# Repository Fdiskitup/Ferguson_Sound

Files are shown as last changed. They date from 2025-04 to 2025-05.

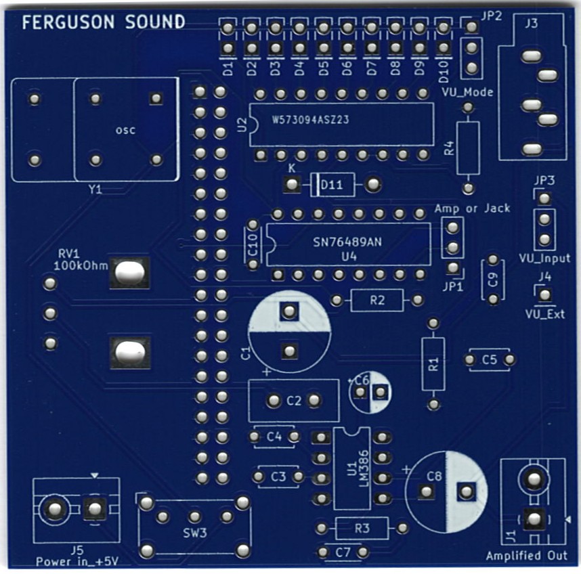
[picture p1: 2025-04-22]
PCB/Ferguson Sound FRONT.JPG

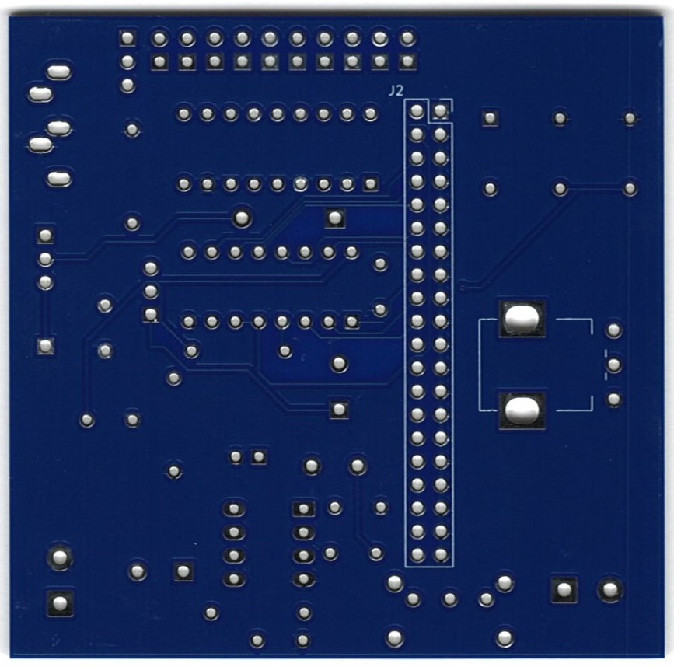
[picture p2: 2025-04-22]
PCB/Ferguson Sound PCB REAR.JPG

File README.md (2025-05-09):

# Ferguson_Sound
A soundcard for the Ferguson Big Board based on the SN76489 PSG sound chip.   
SN76489AN_soundboard1

The parallel port on the Ferguson Big Board uses the Z80 PIO to give 2 x 8bit bidirectional user ports.  
This soundcard was created to make use of port A. 

The board itself is rather simple consisting of 3 parts. 

1, The programmable sound generator chip (PSG) SN76489 and clock crystal oscillator. 
2, The amplifier based on he classic LM386 op amp chip. 
3, The VU meter using LM3915N-1 to pulse the LED's in tune to the music.  

This is derived from several sources 
https://github.com/bchiha/Ready-Z80/tree/main/16-SN76489_Sound_Generator 

https://github.com/jblang/SN76489

https://github.com/abaffa/z80cpm_emulator

What Does it do ? 
well it can output 3 channels of tones simultaneously, like a cord.  plus it can output a 4th noise channel for explosions gunshots etc. 
you can program it from basic, assembly, pascal, C etc.  
remember you will need to set up the PIO Port to be unidirectional - i.e. data mode as output, before trying to send data to the PSG.  
Included here are some basic files to get you started making noises.  
More importantly there is a program here M.COM that will mute the sound chip, because when it first turns on it tends to emit a random tone.  You'll want to stop this.

perhaps more interesting is the ability to play VGM files - these are Video Game Music files. 
The disk images here contain several files "filename.vgm" to play a vgm file simply type : 
VGMPLAY filename.VGM  [then Return/Enter]

to deal with the issue of speed I have recomplied the VGMPLAY.COM with different delays, 4VGMPLAY.COM is fastest while 7VGMPLAY.COM is slowest.
Speed mismatches occur because the PSG clock crystal (4MHZ) used may not be the same as that in the origin system.   

Ferguson Sound FRONT

The 270nF capacitors on the BOM are a strange value but it will be fine with 220nF or 300nF.  Hobby engineering. 

So you've built the card: 

On the Big Board make sure you set the jumpers pins 7-8, 9-10, 11-12, 13-14, 15-16 all on.  This sets the port for output only from the hardware.
see the single blue jumper and the 4 red jumpers.  
FS-1

You'll need to give the board +5V, I just brought a cable from the main board power block to the soundcard power block.  
The ground plane is connected to the 10 ground pins of the connector so you could just wire in a single 5V from the rails directly below the power connector.

JP1 = selects non-amplified or amplified output.  Non amplified goes to the 3.5 mm Jack then into powered speakers.   Amplified out can go direct into a 8ohm speaker or if to connect an RCA jack direct into a TV.   
JP2 = selects bar or dot mode for the VU meter (if installed) 
JP3 = selects to use internal audio for the VU meter, or external input for the VU meter (really just to test it.).    

I have tried with the 4MHZ full size dip 16 crystal oscillator, but I put in the footprint for the smaller oscillator package.  it should accomodate other frequencies 3.57mhz etc.  or you can steal a clock signal from the Z80-PIO pin 25 (Bandit !). 
similarly you can just jumper the power switch so its always on - you can always turn it down with the pot.       

So once it is built and jumpered, switch on and you should be treated to some excellent feedback.  
quickly boot into CPM and run the M.COM file to mute the noise, phew. 

The port resides at 08 and 09 hex

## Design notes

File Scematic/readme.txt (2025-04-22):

I used Kicad 9.0 to create the schematic.  
custom footprints were needed : SN76489, LM3915N-1, the 10kohm pot also needed to be modified to fit.

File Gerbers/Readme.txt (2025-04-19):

These Gerbers were used to make a set of boards with PCBWAY in April of 2025.  The Board was built and tested.  
comments : 
1, The 0.27uF (270nF) caps were substituted with 0.22uF (220nF) ceramics and the amp circuit works fine.
2, The slide switch on the power line stops the random feedback at power on, I did not have the exact switch so used a substitute.  The M.com file mutes the PSG on boot and if needed with a hanging note etc. 
3, The VU meter bottom 2 LED's stay on at all times and the sensitivity of the VU meter is attenuated too much by the volume POT.  Resistor and/or cap values need fine tuning.

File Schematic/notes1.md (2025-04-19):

3 main areas to the schematic 

psg and clock to non amplified output 
amplifier circuit
vu meter circuit 

is possible to make just the psg and leave the rest unpopulated, or psg + amp only

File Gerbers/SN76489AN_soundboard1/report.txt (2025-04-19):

Plotted to 'C:\Users\spenc\OneDrive\Documents\KiCad\9.0\projects\SN76489AN-1\SN76489AN_soundboard1\SN76489AN_soundboard1-F_Cu.gbr'.
Plotted to 'C:\Users\spenc\OneDrive\Documents\KiCad\9.0\projects\SN76489AN-1\SN76489AN_soundboard1\SN76489AN_soundboard1-B_Cu.gbr'.
Plotted to 'C:\Users\spenc\OneDrive\Documents\KiCad\9.0\projects\SN76489AN-1\SN76489AN_soundboard1\SN76489AN_soundboard1-F_Paste.gbr'.
Plotted to 'C:\Users\spenc\OneDrive\Documents\KiCad\9.0\projects\SN76489AN-1\SN76489AN_soundboard1\SN76489AN_soundboard1-B_Paste.gbr'.
Plotted to 'C:\Users\spenc\OneDrive\Documents\KiCad\9.0\projects\SN76489AN-1\SN76489AN_soundboard1\SN76489AN_soundboard1-F_Silkscreen.gbr'.
Plotted to 'C:\Users\spenc\OneDrive\Documents\KiCad\9.0\projects\SN76489AN-1\SN76489AN_soundboard1\SN76489AN_soundboard1-B_Silkscreen.gbr'.
Plotted to 'C:\Users\spenc\OneDrive\Documents\KiCad\9.0\projects\SN76489AN-1\SN76489AN_soundboard1\SN76489AN_soundboard1-F_Mask.gbr'.
Plotted to 'C:\Users\spenc\OneDrive\Documents\KiCad\9.0\projects\SN76489AN-1\SN76489AN_soundboard1\SN76489AN_soundboard1-B_Mask.gbr'.
Plotted to 'C:\Users\spenc\OneDrive\Documents\KiCad\9.0\projects\SN76489AN-1\SN76489AN_soundboard1\SN76489AN_soundboard1-Edge_Cuts.gbr'.
Created Gerber job file 'C:\Users\spenc\OneDrive\Documents\KiCad\9.0\projects\SN76489AN-1\SN76489AN_soundboard1\SN76489AN_soundboard1-job.gbrjob'.
Info: Done.

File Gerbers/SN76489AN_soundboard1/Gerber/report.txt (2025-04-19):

Plotted to 'C:\Users\spenc\OneDrive\Documents\KiCad\9.0\projects\SN76489AN-1\SN76489AN_soundboard1\Gerber\SN76489AN_soundboard1-F_Cu.gbr'.
Plotted to 'C:\Users\spenc\OneDrive\Documents\KiCad\9.0\projects\SN76489AN-1\SN76489AN_soundboard1\Gerber\SN76489AN_soundboard1-B_Cu.gbr'.
Plotted to 'C:\Users\spenc\OneDrive\Documents\KiCad\9.0\projects\SN76489AN-1\SN76489AN_soundboard1\Gerber\SN76489AN_soundboard1-F_Paste.gbr'.
Plotted to 'C:\Users\spenc\OneDrive\Documents\KiCad\9.0\projects\SN76489AN-1\SN76489AN_soundboard1\Gerber\SN76489AN_soundboard1-B_Paste.gbr'.
Plotted to 'C:\Users\spenc\OneDrive\Documents\KiCad\9.0\projects\SN76489AN-1\SN76489AN_soundboard1\Gerber\SN76489AN_soundboard1-F_Silkscreen.gbr'.
Plotted to 'C:\Users\spenc\OneDrive\Documents\KiCad\9.0\projects\SN76489AN-1\SN76489AN_soundboard1\Gerber\SN76489AN_soundboard1-B_Silkscreen.gbr'.
Plotted to 'C:\Users\spenc\OneDrive\Documents\KiCad\9.0\projects\SN76489AN-1\SN76489AN_soundboard1\Gerber\SN76489AN_soundboard1-F_Mask.gbr'.
Plotted to 'C:\Users\spenc\OneDrive\Documents\KiCad\9.0\projects\SN76489AN-1\SN76489AN_soundboard1\Gerber\SN76489AN_soundboard1-B_Mask.gbr'.
Plotted to 'C:\Users\spenc\OneDrive\Documents\KiCad\9.0\projects\SN76489AN-1\SN76489AN_soundboard1\Gerber\SN76489AN_soundboard1-Edge_Cuts.gbr'.
Created Gerber job file 'C:\Users\spenc\OneDrive\Documents\KiCad\9.0\projects\SN76489AN-1\SN76489AN_soundboard1\Gerber\SN76489AN_soundboard1-job.gbrjob'.
Info: Done.

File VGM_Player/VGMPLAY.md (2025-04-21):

The VGM (Video Game Music) player .com file is used by typing :
6VGMPLAY Filename.VGM 
where file name is the name of the VGM you want to play.  simple enough. 
7VGMPLAY.COM and 6VGMPLAY are basically the same but a single NOP delay difference means that 6VGMPLAY.COM plays the files slightly faster.  
Files come in a mixture of formats, VGM files from the BBC micro use a 4mhz clock chip.  Other formats, Sega, etc, use a 3.57 NTSC 60Hz clock.  
Add to that the possibility for a 2.5mhz Ferguson cpu clock with the PSG requirement for 32 clock cycles between data writes and you can see how a variable delay might be needed.  
Ideally we could add it as a command line switch or even a keypress during playback.  A volume attenuation control migt also be nice during playback.  

M.COM   this is the mute ! when the chip turns on it plays whatever random noise is in the buffer.  you'll want to mute it as soon as possible after you boot cpm.

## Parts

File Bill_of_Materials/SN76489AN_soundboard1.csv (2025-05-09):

Reference | Qty | Value | Notes | Footprint | Datasheet/note | Supplier | part | Weblink | DIGIKEY NUMBER
C1,C8 | 2 | 470uF |  | Capacitor_THT:CP_Radial_D10.0mm_P2.50mm | ~ | digikey | UHE1E471MPD6 | https://www.digikey.com/en/products/detail/nichicon/UHE1E471MPD6/589294 |  | Electrolytic
C2 | 1 | 47pF |  | Capacitor_THT:CP_Radial_D5.0mm_P2.50mm | ~ | digikey | CD15ED470JO3 | https://www.digikey.com/en/products/detail/cornell-dubilier-knowles/CD15ED470JO3/337841
C3,C4,C5 | 3 | 270nF |  | Capacitor_THT:CP_Radial_D5.0mm_P2.50mm | 220, 300 use what is close | digikey |  |  |  | Ceramic capacitor
C6 | 1 | 10uF |  | Capacitor_THT:CP_Radial_D5.0mm_P2.50mm | ~ | digikey | 493-13450-1-ND | https://www.digikey.com/en/products/detail/nichicon/UVZ1E100MDD1TD/4342006 |  | Electrolytic
C7,C10 | 2 | 100nF | 0.1uF | Capacitor_THT:CP_Radial_D5.0mm_P2.50mm | ~ | digikey | K104K15X7RF53H5 | https://www.digikey.com/en/products/detail/vishay-beyschlag-draloric-bc-components/K104K15X7RF53H5/2820505
C9 | 1 | 220nF |  | Capacitor_THT:CP_Radial_D5.0mm_P2.50mm | used substitute 300nF |  |  |  |  | Electrolytic
D1 to D10 | 10 | LED |  | LED_THT:LED_D3.0mm | square LED from Ali Express 2mm x 5 mm | ALI Express
D11 | 1 | 1N4007 |  | Diode_THT:D_DO-41_SOD81_P10.16mm_Horizontal | http://www.vishay.com/docs/88503/1n4001.pdf | digikey | 1N4007GOS-ND | https://www.digikey.com/en/products/detail/onsemi/1N4007G/1485479 |  | ceramic
J2 | 1 | GPIO_Header |  | Connector_PinSocket_2.54mm:PinSocket_2x20_P2.54mm_Vertical | Aliexpress
J3 | 1 | AudioJack3_Switch |  | Connector_Audio:Jack_3.5mm_PJ31060-I_Horizontal | mono output only 2 pins needed | digikey | SJ1-3533NG / SJ1-3535NG | https://www.digikey.com/en/products/detail/same-sky-formerly-cui-devices/SJ1-3533NG/738701 https://www.digikey.com/en/products/detail/same-sky-formerly-cui-devices/SJ1-3535NG/738699 |  | might be better top connect, side screws
J4 | 1 | Ext_Pin |  | Connector_PinHeader_2.54mm:PinHeader_1x01_P2.54mm_Horizontal | optional | digikey | 61300311121 | https://www.digikey.com/en/products/detail/w%C3%BCrth-elektronik/61300311121/4846825
J1, J5 | 2 | Power in_+5V, Speaker out |  | TerminalBlock:TerminalBlock_MaiXu_MX126-5.0-02P_1x02_P5.00mm | 5V in and speaker out (consider RF out) |  | 283-5130-ND | https://www.digikey.com/en/products/detail/eaton-electronics-division/EM366002/7718144
R1 | 1 | 1MOhm |  | Resistor_THT:R_Axial_DIN0207_L6.3mm_D2.5mm_P10.16mm_Horizontal | ~ | digikey | A105943CT-ND | https://www.digikey.com/en/products/detail/te-connectivity-passive-product/YR1B1M0CC/2380511
R2,R4 | 2 | 10kOhm |  | Resistor_THT:R_Axial_DIN0207_L6.3mm_D2.5mm_P10.16mm_Horizontal | ~ | digikey | MFR-25FRF52-10K | https://www.digikey.com/en/products/detail/yageo/MFR-25FRF52-10K/14626
R3 | 1 | 10_Ohm |  | Resistor_THT:R_Axial_DIN0207_L6.3mm_D2.5mm_P10.16mm_Horizontal | ~ | digikey | MFR-25FBF52-11R | https://www.digikey.com/en/products/detail/yageo/MFR-25FBF52-11R/4187
RV1 | 1 | 100kOhm |  | Potentiometer_THT:Potentiometer_Bourns_PTV09A-1_Single_Vertical | unique footprint ? | digikey | PDB12-M4251-104BF-ND | https://www.digikey.com/en/products/detail/bourns-inc/PDB12-M4251-104BF/3780670
JP1, SW1, SW2 | 3 | Amp or Jack, VU_Mode, VU_input |  | Connector_PinHeader_2.54mm:PinHeader_1x03_P2.54mm_Vertical | ~ | digikey | 61300311121 | https://www.digikey.com/en/products/detail/w%C3%BCrth-elektronik/61300311121/4846825
SW3 | 1 | Power_Switch |  | Button_Switch_THT:SW_E-Switch_EG1224_SPDT_Angled | (cuts out the noise, volume also works) | digikey | EG2585-ND | https://www.digikey.com/en/products/detail/e-switch/EG1224/502052
U1 | 1 | LM386 |  | Package_DIP:DIP-8-16_W7.62mm_Socket_LongPads | http://www.ti.com/lit/ds/symlink/lm386.pdf | digikey | LM386N-4/NOPB | https://www.digikey.com/en/products/detail/texas-instruments/LM386N-4-NOPB/148192
U2 | 1 | LM3915N |  | Package_DIP:DIP-18_W7.62mm | https://www.ti.com/lit/ds/symlink/lm3914.pdf | ALI Express
U4 | 1 | SN76489AN |  | Package_DIP:DIP-16_W7.62mm | SN76489AN | ALI Express
Y1 | 1 | ACO-4.0MHz |  | Oscillator:Oscillator_DIP-14 | http://www.conwin.com/datasheets/cx/cx030.pdf | EBAY | ECS-2100A-040 | https://www.digikey.com/en/products/detail/ecs-inc/ECS-2100A-040/79196 |  | from Digikey
U2 | 1 | LM3915N |  |  |  | Package_DIP:DIP-18_W7.62mm | https://www.ti.com/lit/ds/symlink/lm3914.pdf |  |  | From Ebay
U4 | 1 | SN76489AN |  |  |  | Package_DIP:DIP-16_W7.62mm | SN76489AN |  |  | From Ali Express
Y1 | 1 | ACO-4.0MHz |  |  |  | Oscillator:Oscillator_DIP-14 | http://www.conwin.com/datasheets/cx/cx030.pdf |  |  | From Ali Express / Digi | https://www.digikey.com/en/products/detail/ecs-inc/ECS-2100A-040/79196

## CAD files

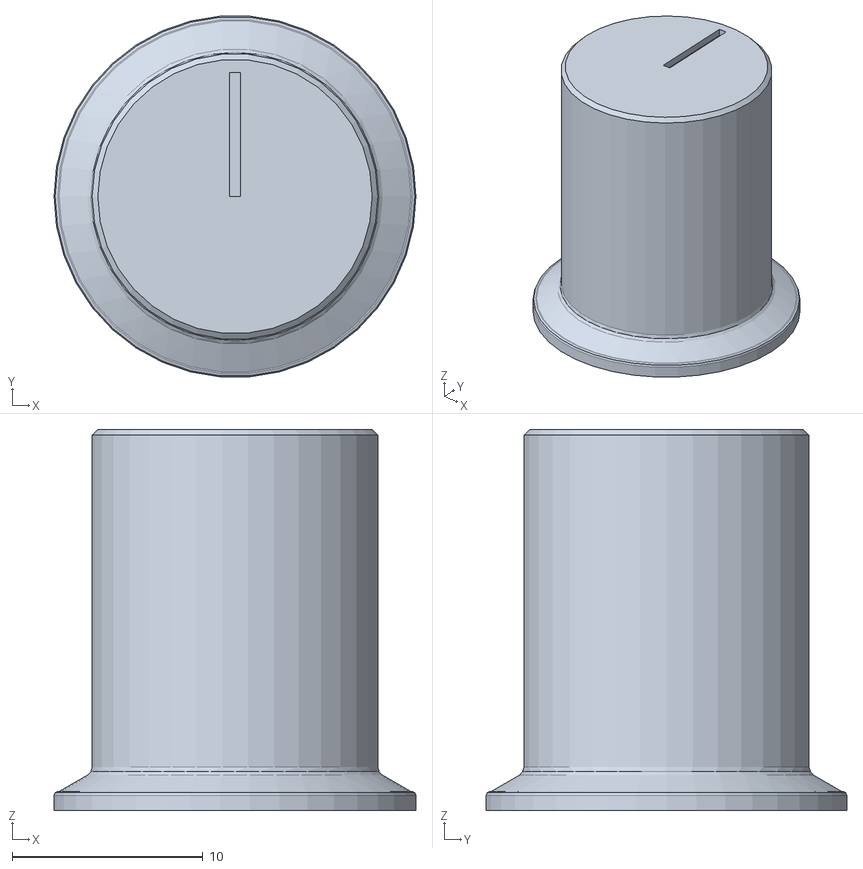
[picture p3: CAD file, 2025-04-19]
3D_prints/Poti_knob.stl
19.0 x 18.9 x 20.0

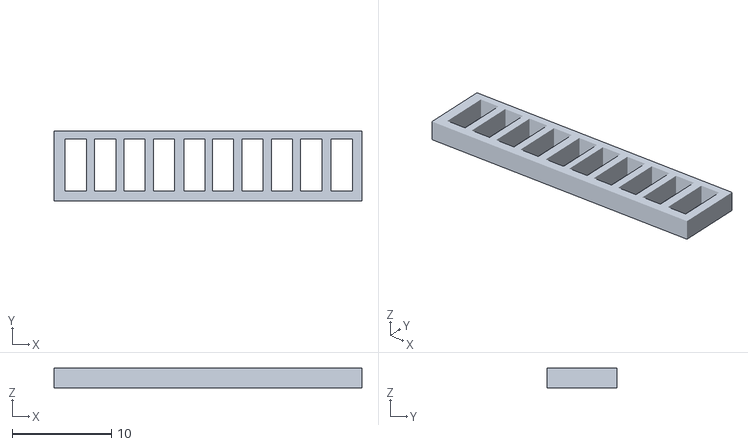
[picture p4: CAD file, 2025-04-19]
3D_prints/led guide.stl
31.0 x 7.00 x 2.00

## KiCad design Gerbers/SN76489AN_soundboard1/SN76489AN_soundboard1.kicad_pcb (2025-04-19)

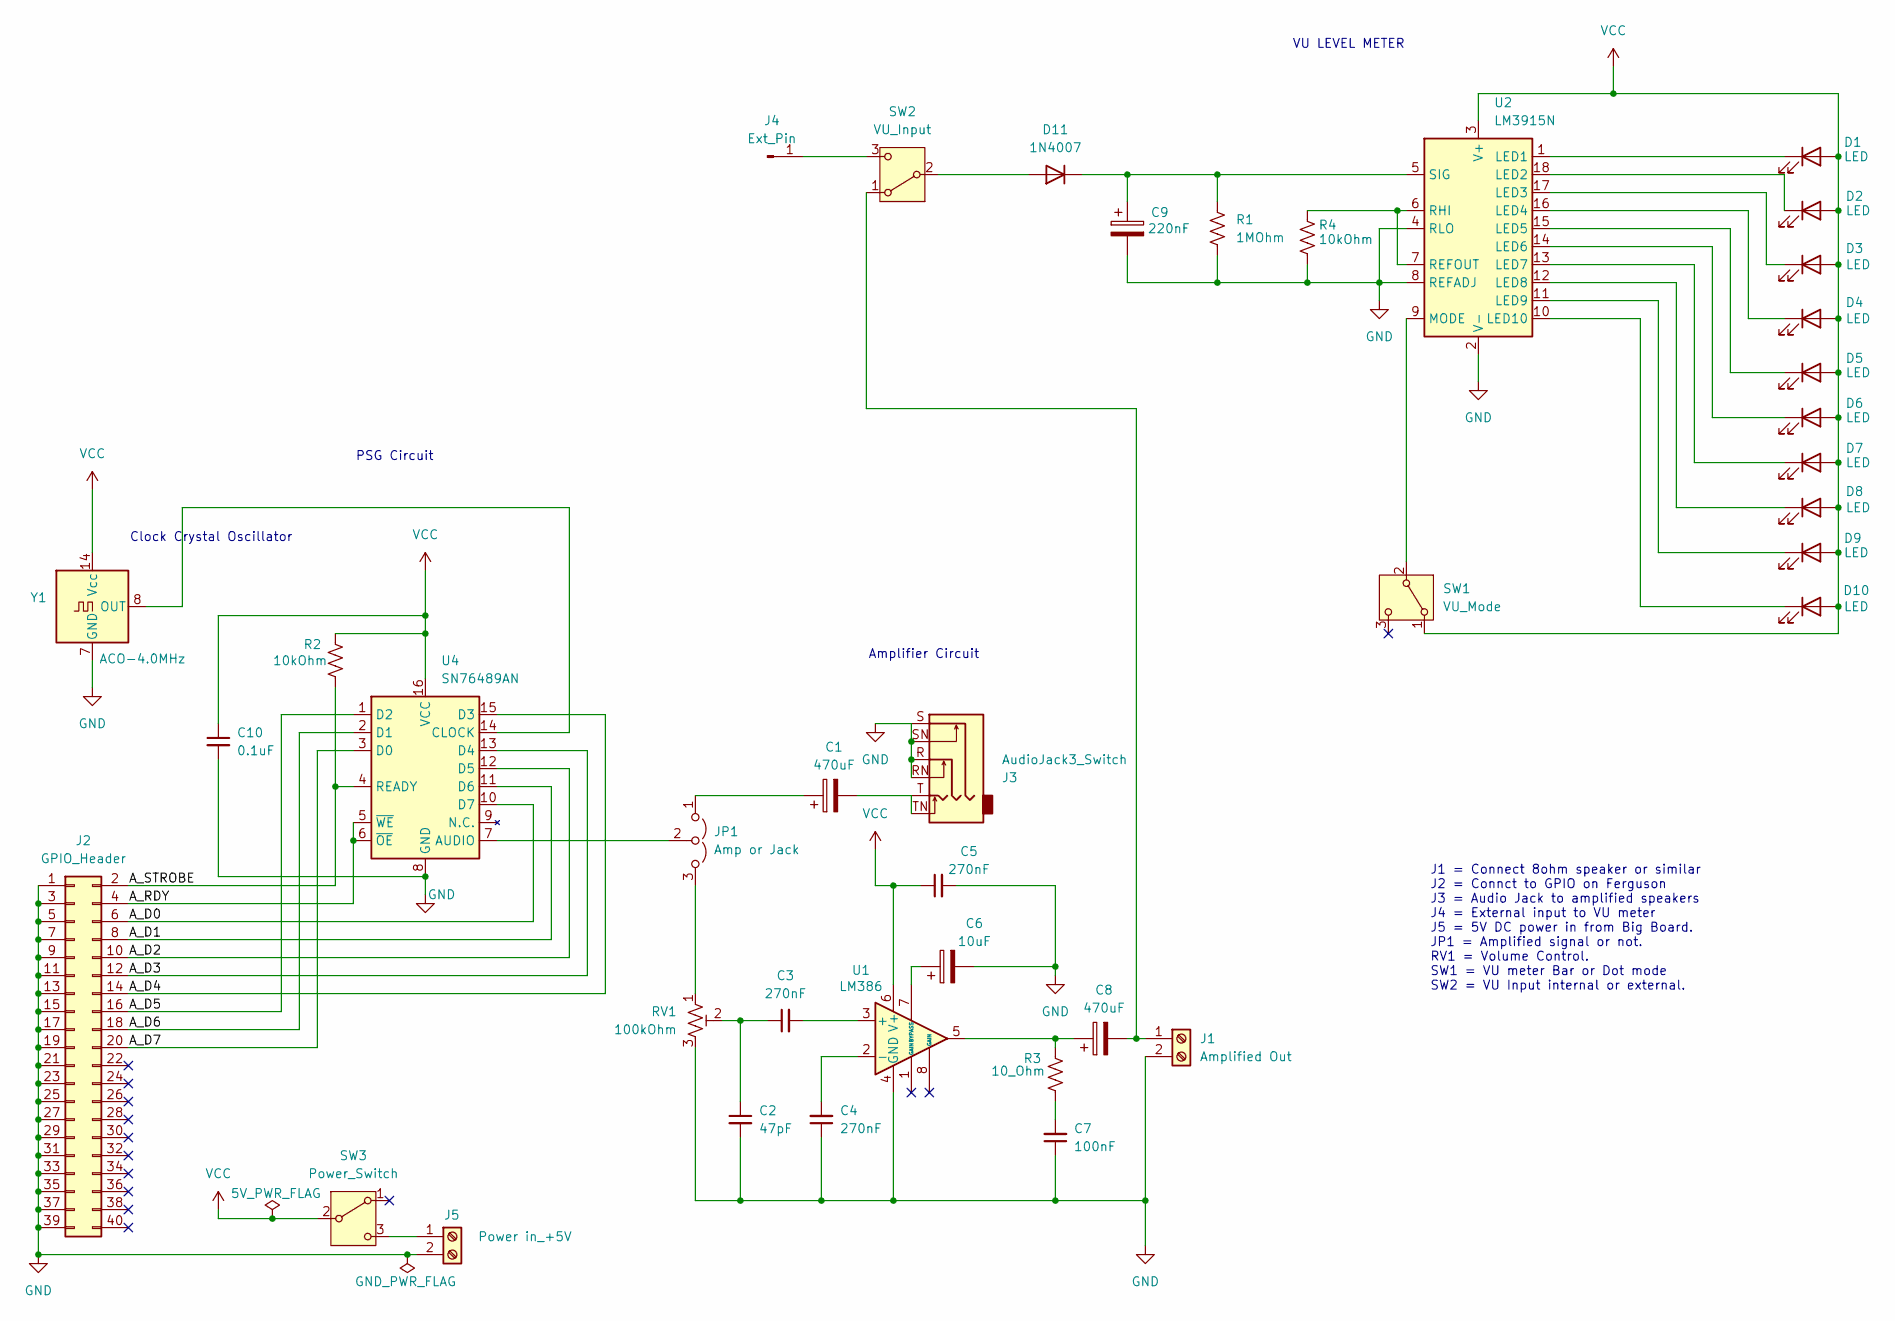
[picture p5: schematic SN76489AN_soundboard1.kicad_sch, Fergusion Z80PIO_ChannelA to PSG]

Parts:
C1: 470uF; CP_Radial_D10.0mm_P2.50mm
C2: 47pF; CP_Radial_D5.0mm_P2.50mm
C3, C4, C5: 270nF; CP_Radial_D5.0mm_P2.50mm
C6: 10uF; CP_Radial_D5.0mm_P2.50mm
C7: 100nF; CP_Radial_D5.0mm_P2.50mm
C8: 470uF; C_Radial_D10.0mm_H12.5mm_P5.00mm
C9: 220nF; CP_Radial_D5.0mm_P2.50mm
C10: 0.1uF; CP_Radial_D5.0mm_P2.50mm
D1, D2, D3, D4, D5, D6, D7, D8, D9, D10: LED; LED_D3.0mm
D11: 1N4007; D_DO-41_SOD81_P10.16mm_Horizontal
J1: Amplified Out; TerminalBlock_MaiXu_MX126-5.0-02P_1x02_P5.00mm
J2: GPIO_Header; PinSocket_2x20_P2.54mm_Vertical
J3: AudioJack3_Switch; Jack_3.5mm_PJ31060-I_Horizontal
J4: Ext_Pin; PinHeader_1x01_P2.54mm_Horizontal
J5: Power in_+5V; TerminalBlock_MaiXu_MX126-5.0-02P_1x02_P5.00mm
JP1: Amp or Jack; PinHeader_1x03_P2.54mm_Vertical
R1: 1MOhm; R_Axial_DIN0207_L6.3mm_D2.5mm_P10.16mm_Horizontal
R2, R4: 10kOhm; R_Axial_DIN0207_L6.3mm_D2.5mm_P10.16mm_Horizontal
R3: 10_Ohm; R_Axial_DIN0207_L6.3mm_D2.5mm_P10.16mm_Horizontal
RV1: 100kOhm; Potentiometer_Bourns_PTV09A-1_Single_Vertical
SW1: VU_Mode; PinHeader_1x03_P2.54mm_Vertical
SW2: VU_Input; PinHeader_1x03_P2.54mm_Vertical
SW3: Power_Switch; SW_E-Switch_EG1224_SPDT_Angled
U1: LM386; DIP-8-16_W7.62mm_Socket_LongPads
U2: LM3915N; DIP-18_W7.62mm
U4: SN76489AN; DIP-16_W7.62mm
Y1: ACO-4.0MHz; Oscillator_DIP-14

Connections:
/A_D0: J2.6, U4.10 (D7)
/A_D1: J2.8, U4.11 (D6)
/A_D2: J2.10, U4.12 (D5)
/A_D3: J2.12, U4.13 (D4)
/A_D4: J2.14, U4.15 (D3)
/A_D5: J2.16, U4.1 (D2)
/A_D6: J2.18, U4.2 (D1)
/A_D7: J2.20, U4.3 (D0)
/A_RDY: J2.4, U4.5 (~WE), U4.6 (~OE)
/A_STROBE: J2.2, R2.2, U4.4 (READY)
GND: C2.2, C4.1, C5.2, C6.2, C7.1, C9.2, C10.2, J1.2, J2.1, J2.3, J2.5, J2.7, J2.9, J2.11, J2.13, J2.15, J2.17, J2.19, J2.21, J2.23, J2.25, J2.27, J2.29, J2.31, J2.33, J2.35, J2.37, J2.39, J3.R, J3.RN, J3.S, J3.SN, J5.2, R1.2, R4.2, RV1.3, U1.4 (GND), U2.2 (V-), U2.4 (RLO), U2.8 (REFADJ), U4.8 (GND), Y1.7 (GND); also elsewhere on the board
unnamed: C1.2, J3.T, J3.TN
unnamed: C2.1, C3.1, RV1.2
unnamed: C7.2, R3.2
unnamed: C8.1, R3.1, U1.5
unnamed: D1.1 (K), U2.1 (LED1)
unnamed: D2.1 (K), U2.18 (LED2)
unnamed: D3.1 (K), U2.17 (LED3)
unnamed: D4.1 (K), U2.16 (LED4)
unnamed: D5.1 (K), U2.15 (LED5)
unnamed: D6.1 (K), U2.14 (LED6)
unnamed: D7.1 (K), U2.13 (LED7)
unnamed: D8.1 (K), U2.12 (LED8)
unnamed: D9.1 (K), U2.11 (LED9)
unnamed: D10.1 (K), U2.10 (LED10)
unnamed 25: D11.2 (A), SW2.2 (B); also elsewhere on the board
unnamed: C9.1, D11.1 (K), R1.1, U2.5 (SIG)
unnamed 27: C8.2, J1.1, SW2.1 (A); also elsewhere on the board
unnamed 28: J4.1, SW2.3 (C); also elsewhere on the board
unnamed: J5.1, SW3.3 (C)
unnamed: C1.1, JP1.1 (A)
unnamed: JP1.3 (B), RV1.1
unnamed: JP1.2 (C), U4.7 (AUDIO)
unnamed 33: SW1.2 (B), U2.9 (MODE); also elsewhere on the board
unnamed: C3.2, U1.3 (+)
unnamed: C4.2, U1.2 (-)
unnamed: C6.1, U1.7 (BYPASS)
unnamed: R4.1, U2.6 (RHI), U2.7 (REFOUT)
unnamed 38: U4.14 (CLOCK), Y1.8 (OUT); also elsewhere on the board
VCC: C5.1, C10.1, D1.2 (A), D2.2 (A), D3.2 (A), D4.2 (A), D5.2 (A), D6.2 (A), D7.2 (A), D8.2 (A), D9.2 (A), D10.2 (A), R2.1, SW1.1 (A), SW3.2 (B), U1.6 (V+), U2.3 (V+), U4.16 (VCC), Y1.14 (Vcc); also elsewhere on the board

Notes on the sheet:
PSG Circuit
J1 = Connect 8ohm speaker or similar J2 = Connct to GPIO on Ferguson J3 = Audio Jack to amplified speakers J4 = External input to VU meter J5 = 5V DC power in from Big Board. JP1 = Amplified signal or not. RV1 = Volume Control. SW1 = VU meter Bar or Dot mode SW2 = VU Input internal or external.
Clock Crystal Oscillator
Amplifier Circuit
VU LEVEL METER

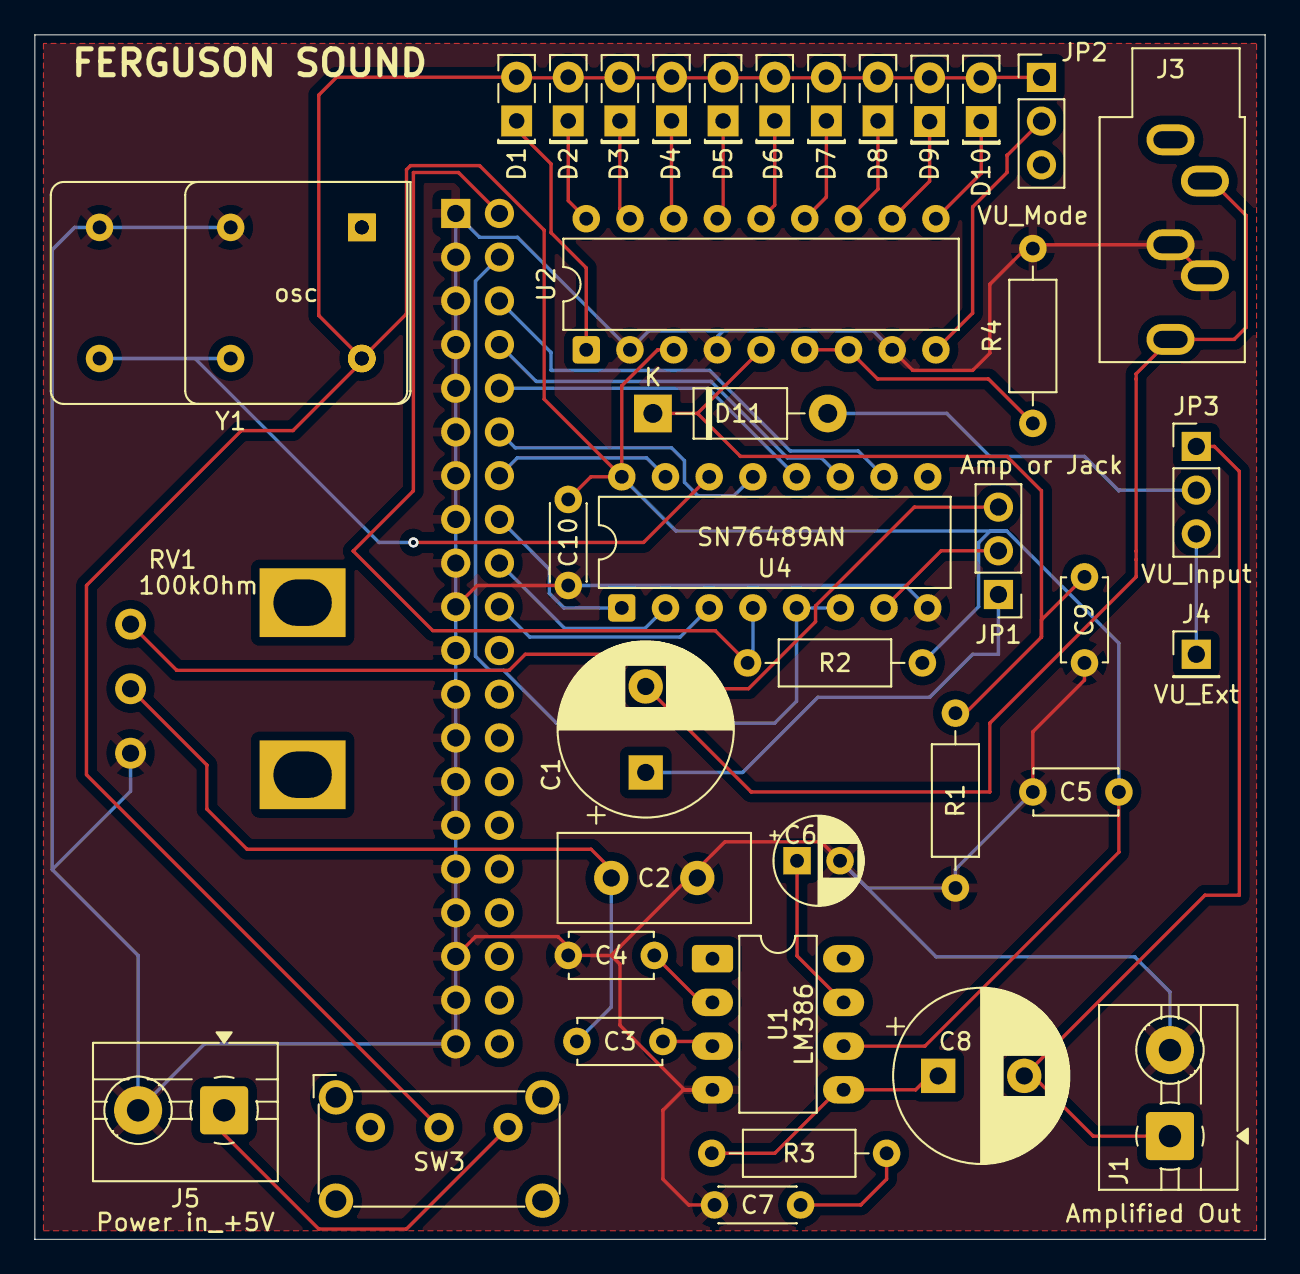
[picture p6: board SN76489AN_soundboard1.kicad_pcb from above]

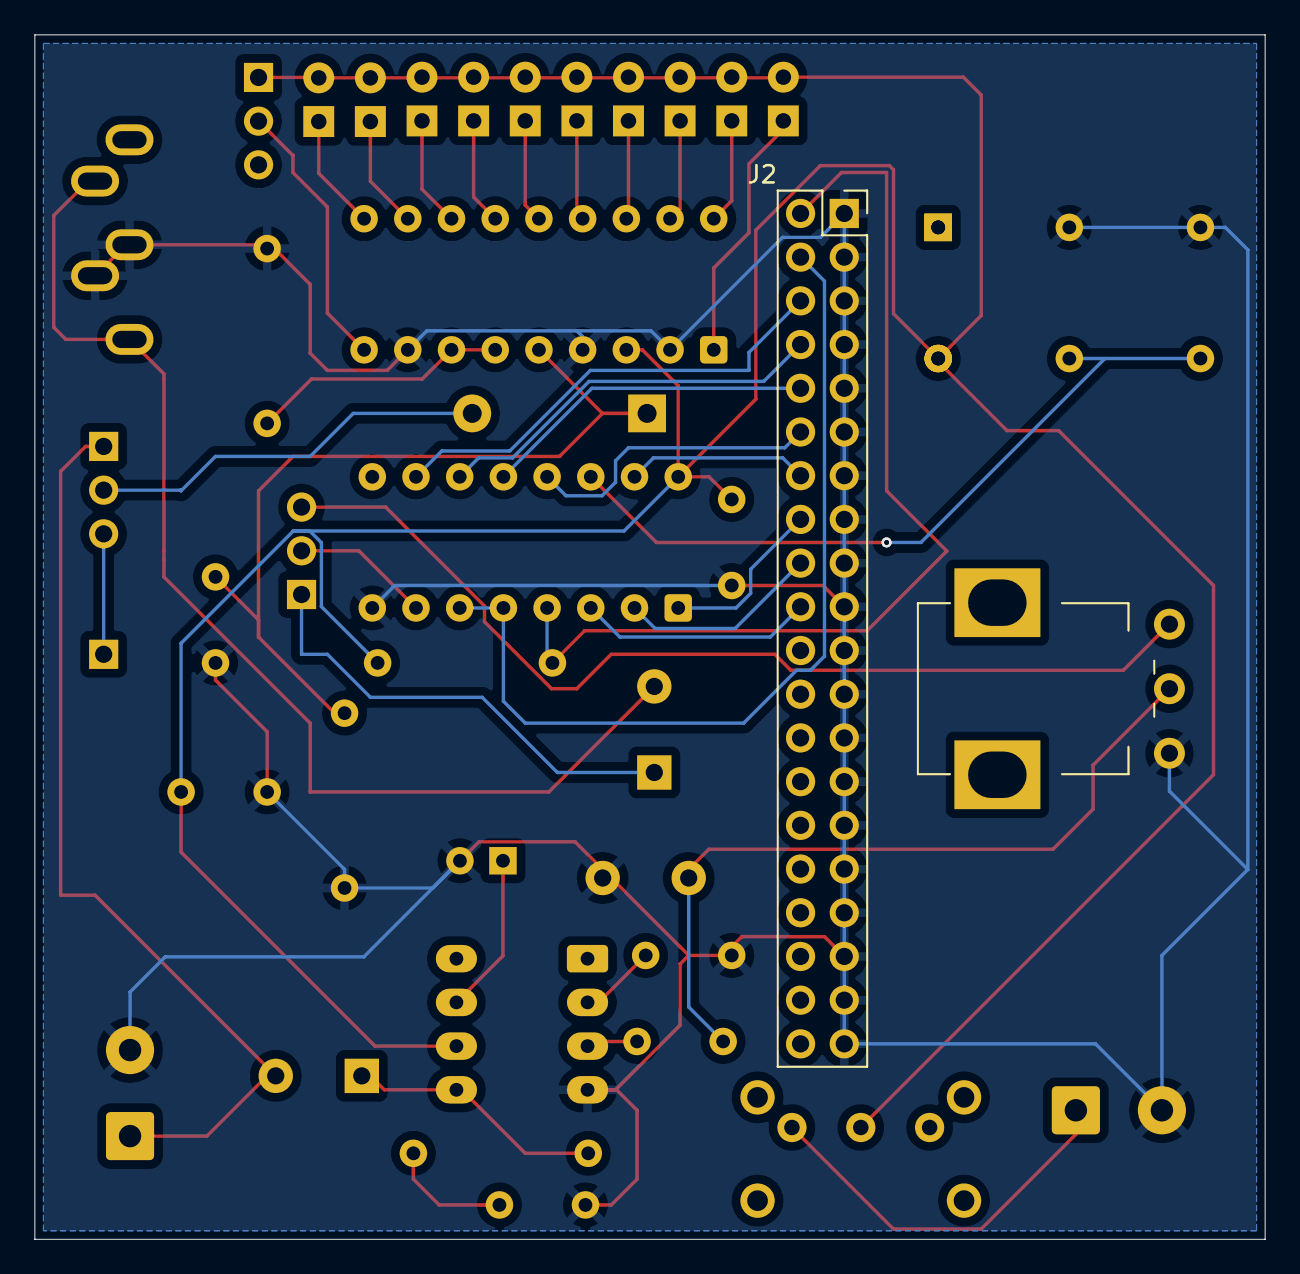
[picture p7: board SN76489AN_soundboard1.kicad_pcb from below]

Board: 2 copper layers, 71.5 x 70.0 mm, 40 parts (2 on the bottom side), 40 nets.

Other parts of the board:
JP2: VU_Mode; PinHeader_1x03_P2.54mm_Vertical
JP3: VU_Input; PinHeader_1x03_P2.54mm_Vertical
osc: Oscillator_DIP-8

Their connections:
GND: osc.4; also elsewhere on the board
unnamed 25: JP3.2 (B); also elsewhere on the board
unnamed 27: JP3.1 (A); also elsewhere on the board
unnamed 28: JP3.3 (C); also elsewhere on the board
unnamed 33: JP2.2 (B); also elsewhere on the board
unnamed 38: osc.5; also elsewhere on the board
VCC: JP2.1 (A), osc.8; also elsewhere on the board

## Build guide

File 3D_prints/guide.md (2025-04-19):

heres the picture of the LED Guide 10 LEDs 5mm x 2 mm 
I found with my printer is was necessesary to make the apeture 2.15mm x 5.20mm.  

This literally took me 3 hours iterating the size, slicing, printing, testing.  not very smart. 
The GCode is for my "CREALITY ENDER 3 PRO MAX" printer - recomend you slice it yourself as required. 
LED_Guide_slice

and heres the pot knob "pot Knob.STL" 
https://www.thingiverse.com/thing:1419579

b5d5081061c923004a01fd6a3e6d637a

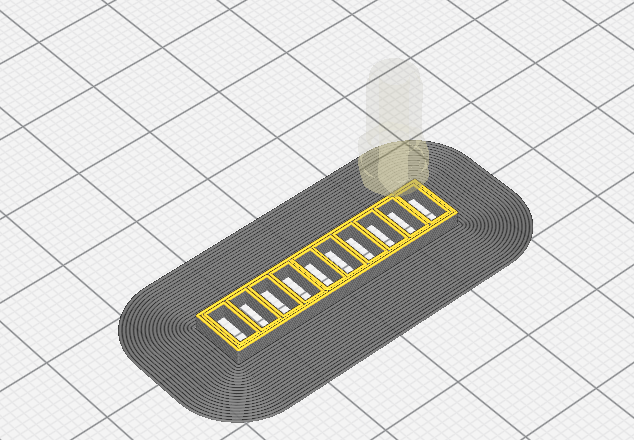
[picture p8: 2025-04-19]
3D_prints/LED_Guide_slice.png

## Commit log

2025-04-19 Add files via upload
    VGMPLAYER for CPM on the Fergusson Big Board. Compiled COM file is for the 4MHz Big Board and the Ferguson Sound card with a 4MHz crystal.
2025-04-19 Add files via upload
    ferguson_sound.zip is the file you need to upload to PCB manufacturing house JLPCB or PCBWAY
    [SN76489AN_soundboard1-B_Cu.gbr, SN76489AN_soundboard1-B_Mask.gbr, SN76489AN_soundboard1-B_Paste.gbr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]
2025-04-19 Create LED_Alignment
2025-05-09 Add files via upload
    added part numbers for ordering from Digikey
    [SN76489AN_soundboard1.csv, SN76489AN_soundboard1.xlsx]
